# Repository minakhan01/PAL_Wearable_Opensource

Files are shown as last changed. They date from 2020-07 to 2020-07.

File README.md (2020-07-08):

# Project PAL
PAL is a  wearable platform for personalized, context-aware, and always-present user change.  PAL has multimodal sensors (camera, location, movement, heart rate, and on-device deep learning) to recognize user context context-aware, e.g., people, indoor locations, objects, etc. On-device deep learning minimizes computation time to provide real-time and offline context-aware support, and user data is also more private as raw data is not sent to the cloud. PAL offers personalized support for each user and users can train custom trainable low-shot models for personalized context detection and support. 

We are currently exploring  PAL for real-world-loop behavior change support using reinforcement learning for closed-loop behavior change interventions. PAL can also be used for real-time cognitive support (e.g., memory augmentation) and visual assistance (e.g., for visually impaired).

https://www.media.mit.edu/projects/pal/overview/

## Table of Contents

- [Layout](#layout)
- [Contents](#contents)
- [Maintainers](#maintainers)
- [Contributors](#contributors)
- [License](#license)

### Layout
    .
    ├── Raspberry Pi  
    │     ├── Codebase         # Node.js and python scripts codebase
    │     ├── Electronics      # Raspberry Pi Shield
    │     └── Hardware         # 3D Design Files for raspberry pi case
    ├── Android App            # Android App (connect to raspberry pi)
    ├── PWA                    # Web App (Habit Tracking)
    ├── Docs                   # Documentation Files
    ├── LICENSE
    └── README.md
    
### Contents
This repository consists of 3 main codebases.
1. Raspberry Pi
   * Codebase: Node.js sever for data collection using sensors and python scripts for data processing.
   * Electronics: Schematics and board files for the raspberry pi shield.
   * Hardware: Design files for 3D printing the raspberry pi case, earhook and microphone cover. 
   
2. The Androd App, to connect to the raspberry pi
   * The Android App connects to the raspberry pi via bluetooth to control the sensors onboard.
   
3. The Progressive Web App, to track ones habits and visualize one's data
    * Real time data visualization and habit tracking 

### Maintainers

### Contributors
This project exists thanks to all the people who contribute.

### License

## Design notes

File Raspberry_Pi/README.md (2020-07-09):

## SD CARD Setup

_IMAGE Version : 2019-09-26-raspbian-buster-lite_

### A. Setting up RTC
1. sudo apt-get install python-smbus i2c-tools
2. sudo nano /boot/config.txt, add 'dtoverlay=i2c-rtc,pcf8523' to file and uncomment 'dtparam=i2c_arm=on'
3. sudo reboot
4. sudo i2c-detect -y 1
5. sudo apt-get -y remove fake-hwclock 
6. sudo update-rc.d -f fake-hwclock remove
7. sudo systemctl disable fake-hwclock
8. sudo nano /lib/udev/hwclock-set and comment out these three lines: 
  ```
  #if [ -e /run/systemd/system ] ; then
  # exit 0
  #fi
```
```
/sbin/hwclock --rtc=$dev --systz --badyear
```
```
/sbin/hwclock --rtc=$dev --systz
```
9. sudo hwclock -D -r
10. date
11. sudo hwclock -w
12. sudo hwclock -r

### B. Setting up I2S Mic
1. sudo nano /boot/config.txt -> Uncomment #dtparam=i2s=on
2. sudo nano /etc/modules -> Add snd-bcm2835 on its own line
3. sudo reboot
4. lsmod | grep snd
5. sudo apt-get update
6. sudo apt-get install rpi-update
7. sudo rpi-update
8. sudo apt-get install git bc libncurses5-dev bison flex libssl-dev
9. sudo wget https://raw.githubusercontent.com/notro/rpi-source/master/rpi-source -O /usr/bin/rpi-source
10. sudo chmod +x /usr/bin/rpi-source
11. /usr/bin/rpi-source -q --tag-update
12. rpi-source --skip-gcc
13. Code coverage for fuzzing (KCOV) [N/y/?] (NEW)  -> enter and continue
14. sudo mount -t debugfs debugs /sys/kernel/debug
15. git clone https://github.com/PaulCreaser/rpi-i2s-audio
16. cd rpi-i2s-audio
17. make -C /lib/modules/$(uname -r )/build M=$(pwd) modules
18. sudo insmod my_loader.ko
19. lsmod | grep my_loader
20. dmesg | tail
21. sudo cp my_loader.ko /lib/modules/$(uname -r)
22. echo 'my_loader' | sudo tee --append /etc/modules > /dev/null
23. sudo depmod -a
24. sudo modprobe my_loader
25. sudo reboot
26. arecord -l
27. arecord -D plughw:1 -c1 -r 48000 -f S32_LE -t wav -V mono -v file.wav
28. aplay file.wav
29. scp pi@<local-ip>:/home/pi/file.wav ~/Desktop/file.wav
30. sudo nano ~/.asoundrc  ->  
```
pcm.dmic_hw {
	type hw
	card sndrpisimplecar
	channels 2
	format S32_LE
}
	type softvol
	slave.pcm dmic_hw
	control {
		name "Boost Capture Volume"
		card sndrpisimpleca
	}
	min_dB -3.0
	max_dB 30.0
}
 ```
31. arecord -D dmic_sv -c2 -r 44100 -f S32_LE -t wav -V mono -v file.wav
32. arecord -D dmic_sv -c2 -r 48000 -f S32_LE -t wav -V mono -v recording.wav
33. aplay recording.wav

### C. IMU Installation
1. sudo pip3 install --upgrade setuptools
2. pip3 install RPI.GPIO
3. pip3 install adafruit-blinka
4. sudo pip3 install adafruit-circuitpython-adxl34x

### D. Pulse Sensor Installation
1. git clone https://github.com/tutRPi/Raspberry-Pi-Heartbeat-Pulse-Sensor
2. sudo python example.py

### E. Speaker
1. pin 12 -> ALT0 && pin 18 -> ALT5

### F. Network Manager
1. npm install node-wifi @google-cloud/storage python-shell
2. sudo apt install network-manager network-manager-gnome openvpn
3. sudo apt install openvpn-systemd-resolved network-manager-openvpn
4. sudo apt install network-manager-openvpn-gnome
5. sudo apt purge openresolv dhcpcd5
6. sudo ln -sf /lib/systemd/resolv.conf /etc/resolv.conf

### G. Bluetooth
1. sudo apt-get install libdbus-1-dev libglib2.0-dev libudev-dev libical-dev libreadline-dev -y
2. wget www.kernel.org/pub/linux/bluetooth/bluez-5.50.tar.xz
3. tar xvf bluez-5.50.tar.xz && cd bluez-5.50
4. ./configure --prefix=/usr --mandir=/usr/share/man --sysconfdir=/etc --localstatedir=/var --enable-experimental
5. make -j4
6. sudo make install
7. sudo reboot
8. ./bluez-5.50/test/example-advertisement
9. sudo service bluetooth stop
10. sudo hciconfig hci0 up # reactivate hci0 or another hciX you want to use 
11. npm install bleno --save

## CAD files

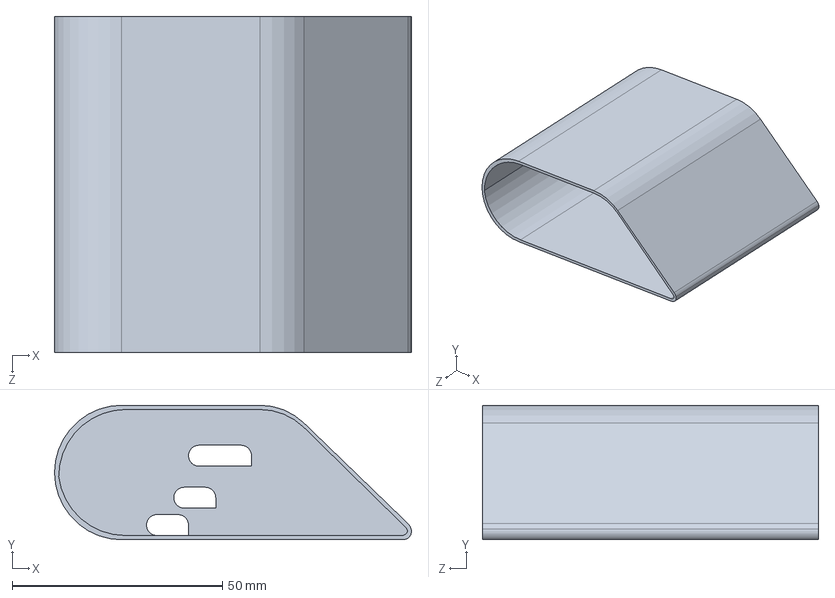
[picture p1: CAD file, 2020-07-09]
Raspberry_Pi/Hardware/source_solidworks/main.SLDPRT
85.0 x 32.0 x 80.0 mm

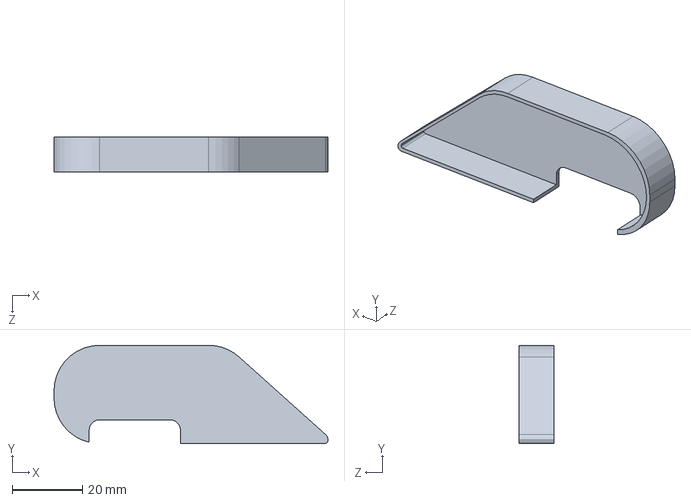
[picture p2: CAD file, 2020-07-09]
Raspberry_Pi/Hardware/source_solidworks/lid.SLDPRT
78.0 x 28.0 x 10.0 mm

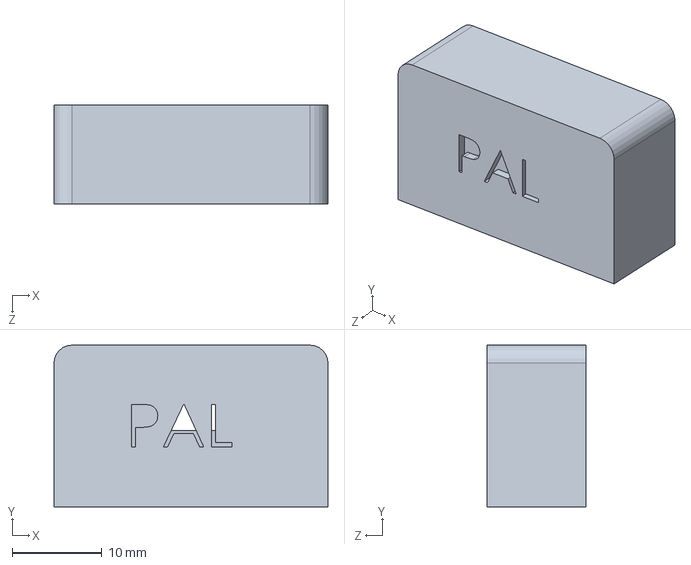
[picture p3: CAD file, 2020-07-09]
Raspberry_Pi/Hardware/source_solidworks/mic.SLDPRT
30.5 x 18.0 x 11.0 mm

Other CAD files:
Raspberry_Pi/Hardware/stl/lid.STL
Raspberry_Pi/Hardware/stl/main.STL
Raspberry_Pi/Hardware/stl/mic.STL

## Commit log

2020-07-09 Added source_solidworks files and stl files
    [lid.SLDPRT, lid.STL, main.SLDPRT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]
2020-07-10 Raspi shield and mic board files added
    [PAL_mic_board_v1.sch, PAL_shield.sch]
